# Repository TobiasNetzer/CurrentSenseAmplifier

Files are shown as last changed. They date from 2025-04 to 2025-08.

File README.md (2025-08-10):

## High-Side current sense amplifier for precise current measurement (up to 100mA)
This high-side current sense amplifier is designed to enable accurate current measurement up to 100mA while maintaining a low burden voltage of 1mV/mA.
With a gain of 100, the amplifier produces an output voltage of 100mV/mA.

Documentation
- [Schematic](https://github.com/TobiasNetzer/CurrentSenseAmplifier/blob/main/Documentation/Schematic.pdf)
- [Assembly Drawing](https://github.com/TobiasNetzer/CurrentSenseAmplifier/blob/main/Documentation/Assembly%20Drawing.pdf)
- [BOM](https://htmlpreview.github.io/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)

---

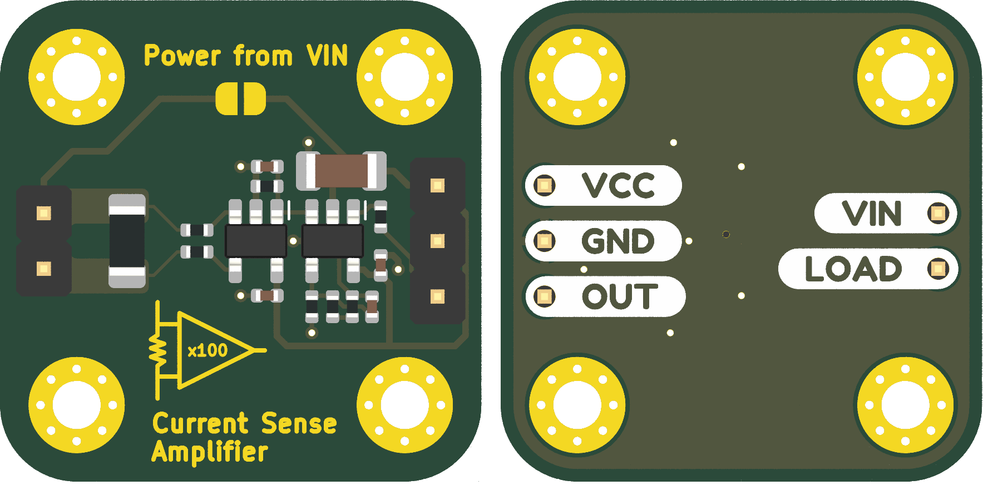
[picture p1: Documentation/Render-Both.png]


---

## Amplifier Accuracy

To test the accuracy of the current sense amplifier, various load currents are applied, and the amplifier’s output is compared to the corresponding load currents. The measurement error is then calculated and plotted as the deviation in percent from the actual value.

Across the tested current range form 5mA - 100mA, the error remained within ±0.2%.

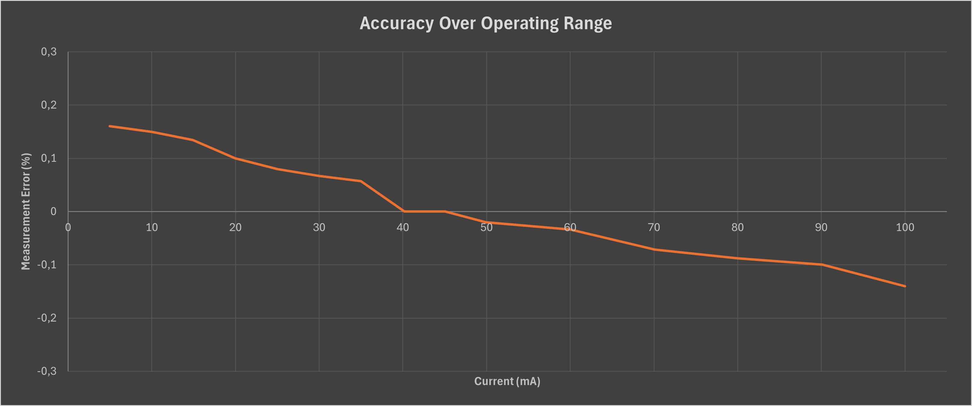
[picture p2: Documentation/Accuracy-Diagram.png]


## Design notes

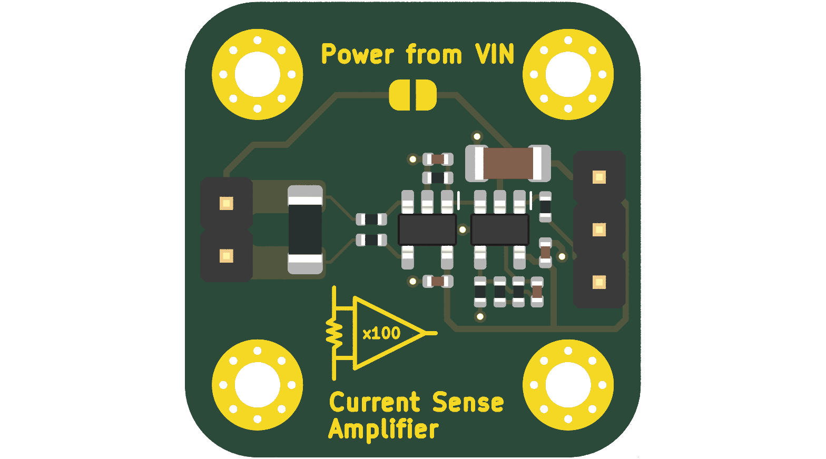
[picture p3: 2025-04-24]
Documentation/Render Top.png

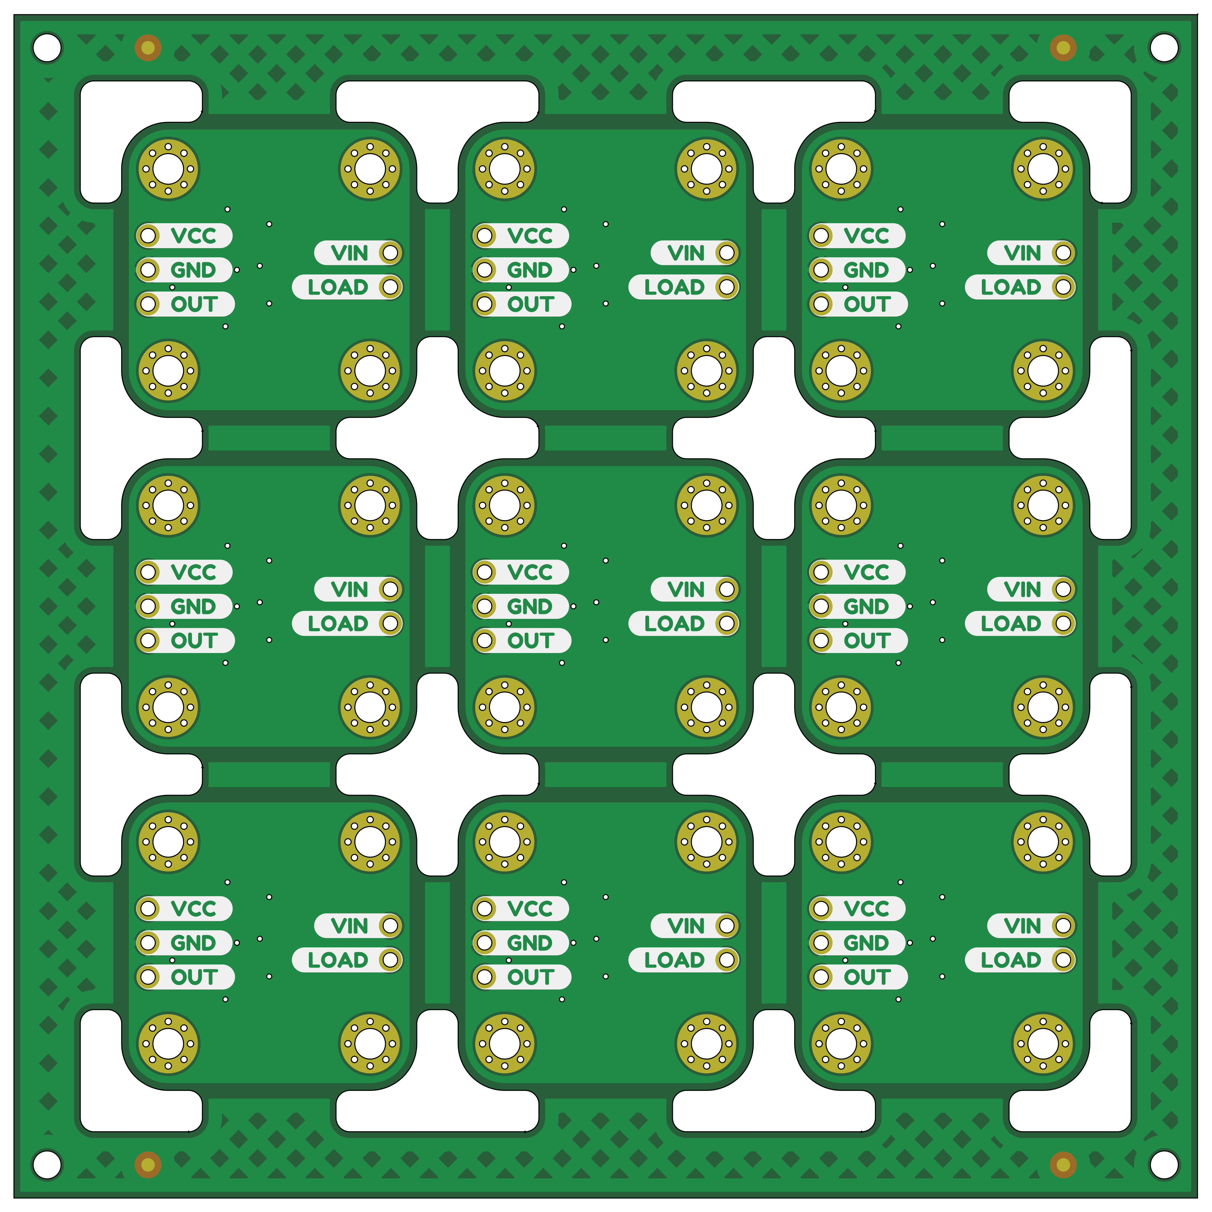
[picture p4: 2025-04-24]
Documentation/Panel Bot Render.png

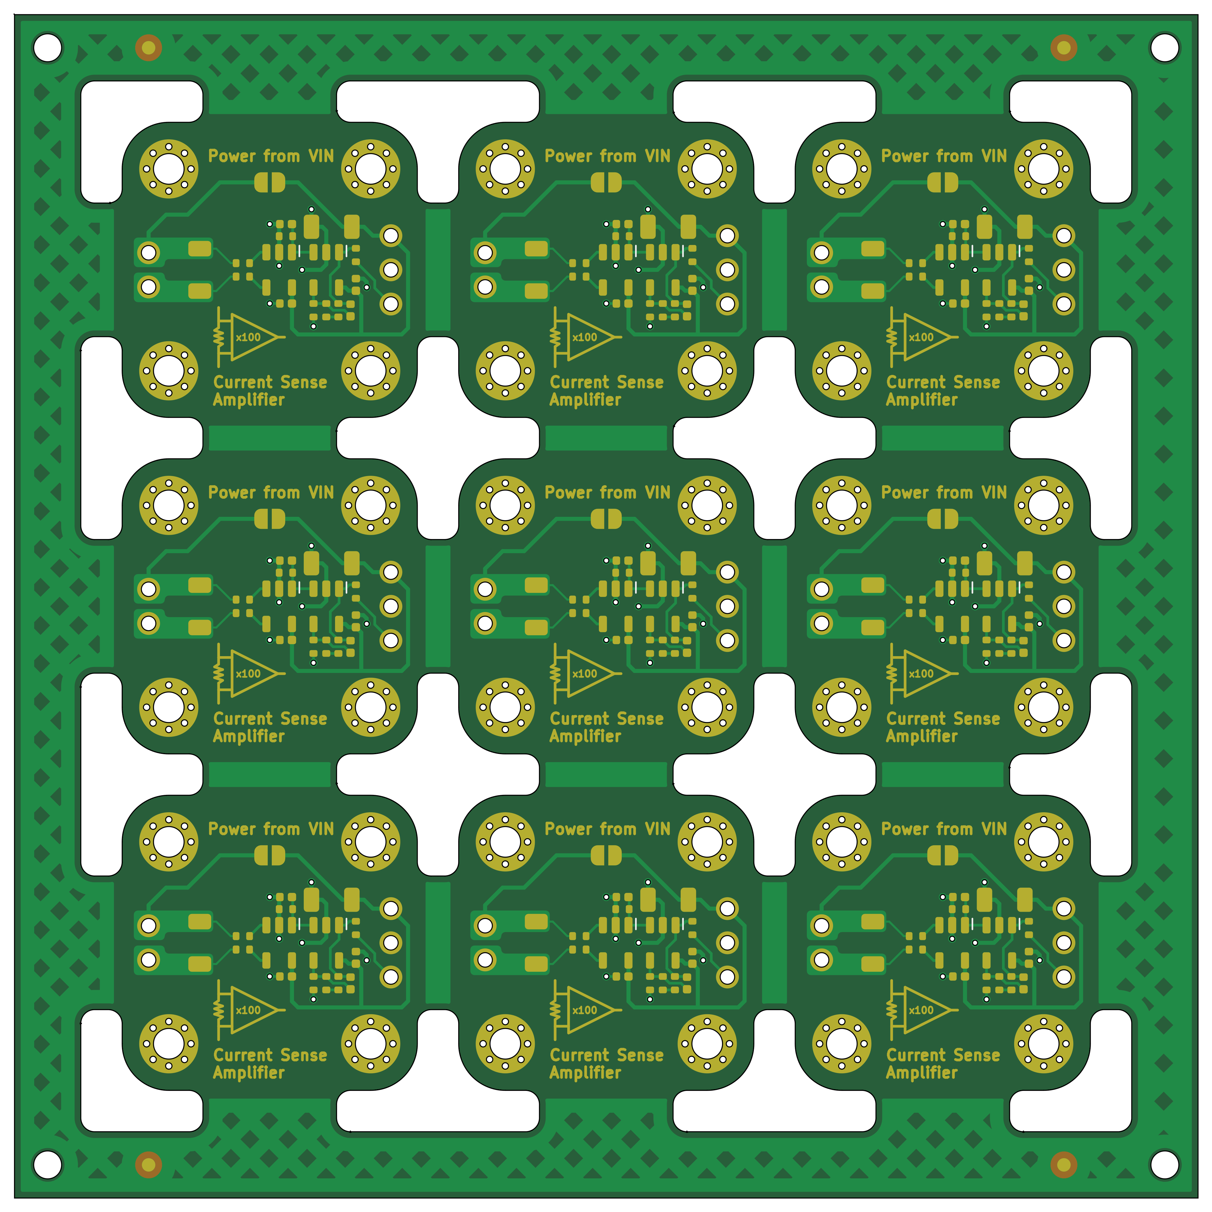
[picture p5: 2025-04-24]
Documentation/Panel Top Render.png

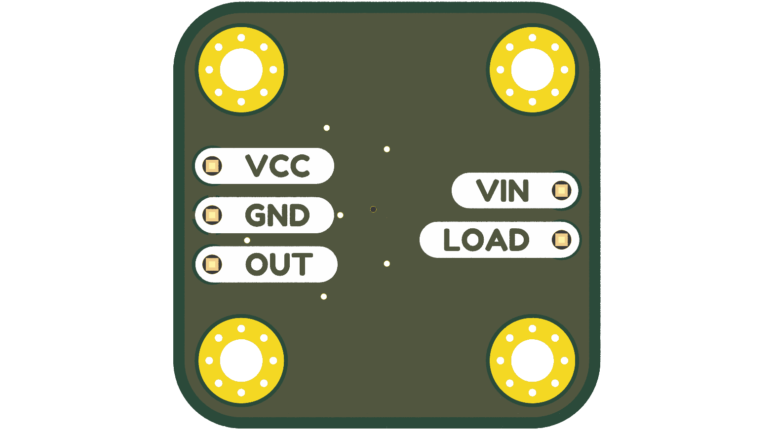
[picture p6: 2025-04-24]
Documentation/Render Bot.png

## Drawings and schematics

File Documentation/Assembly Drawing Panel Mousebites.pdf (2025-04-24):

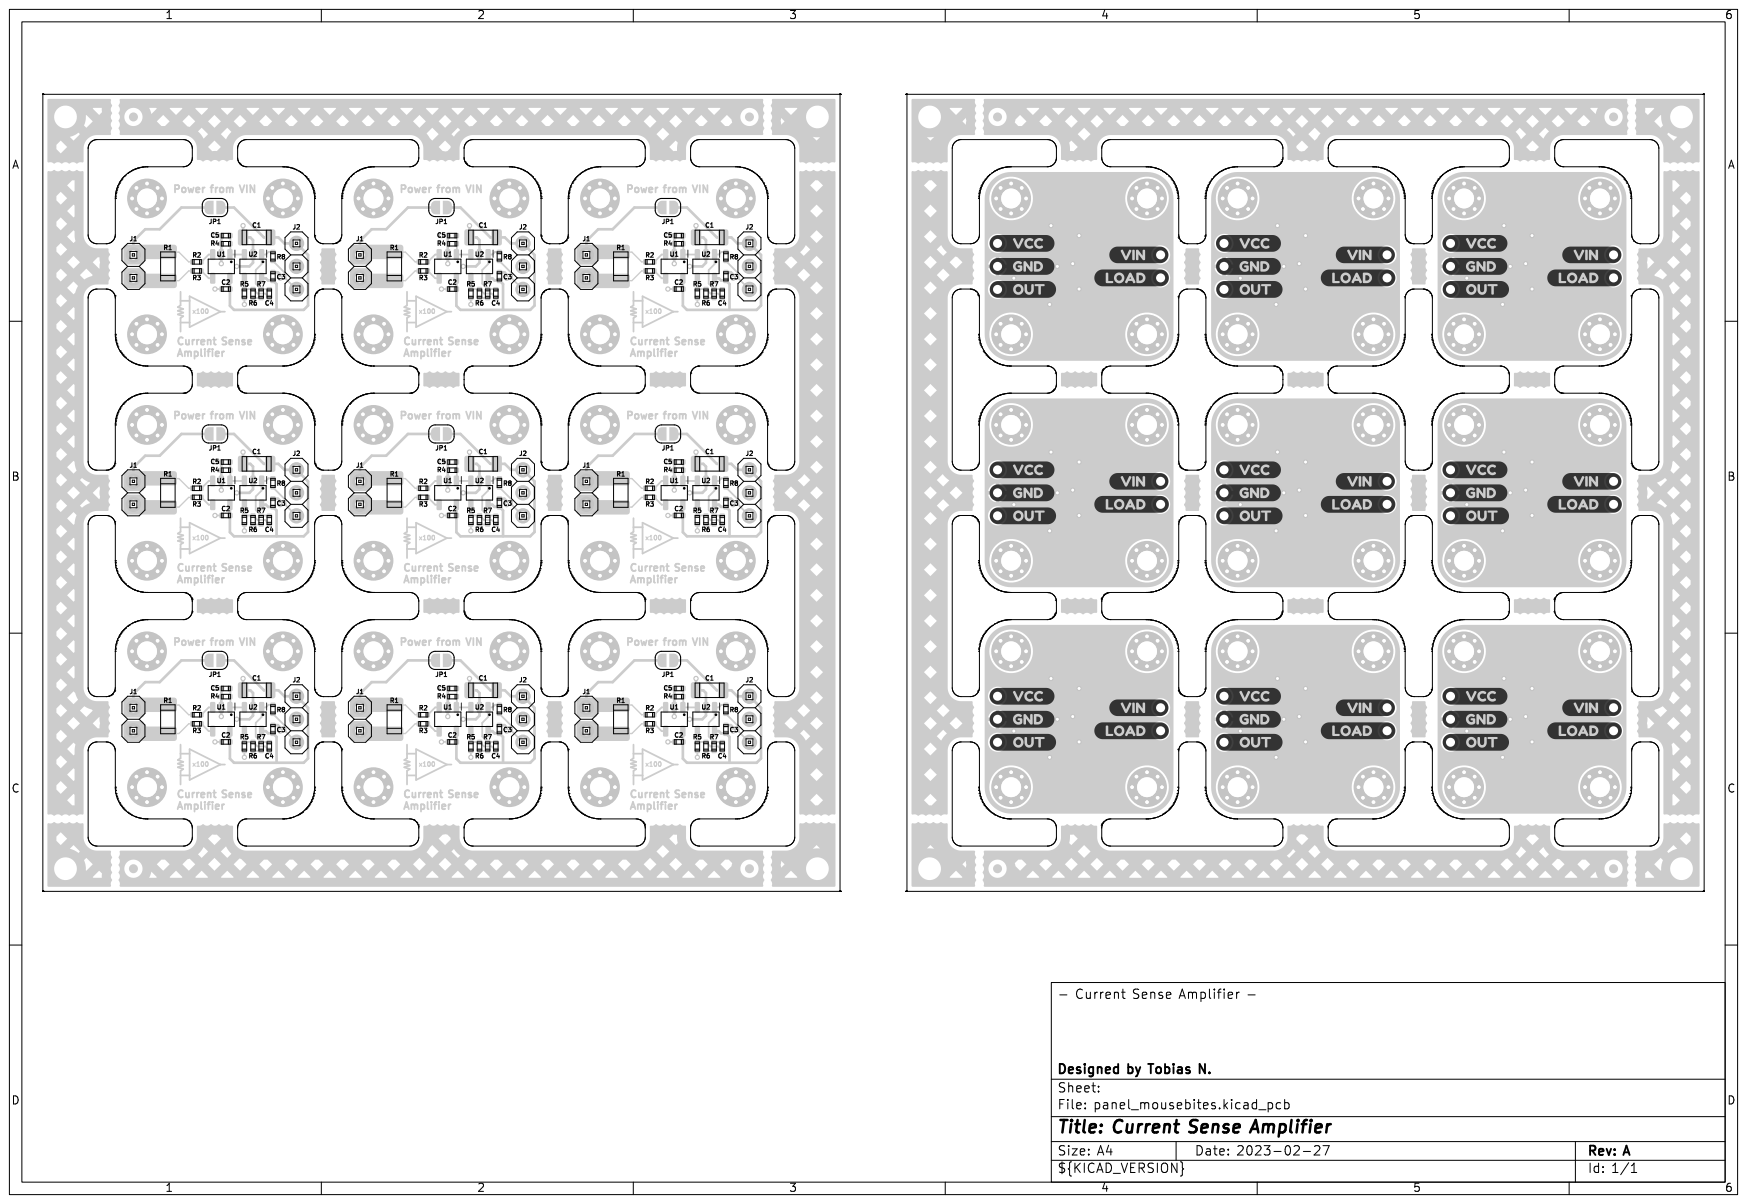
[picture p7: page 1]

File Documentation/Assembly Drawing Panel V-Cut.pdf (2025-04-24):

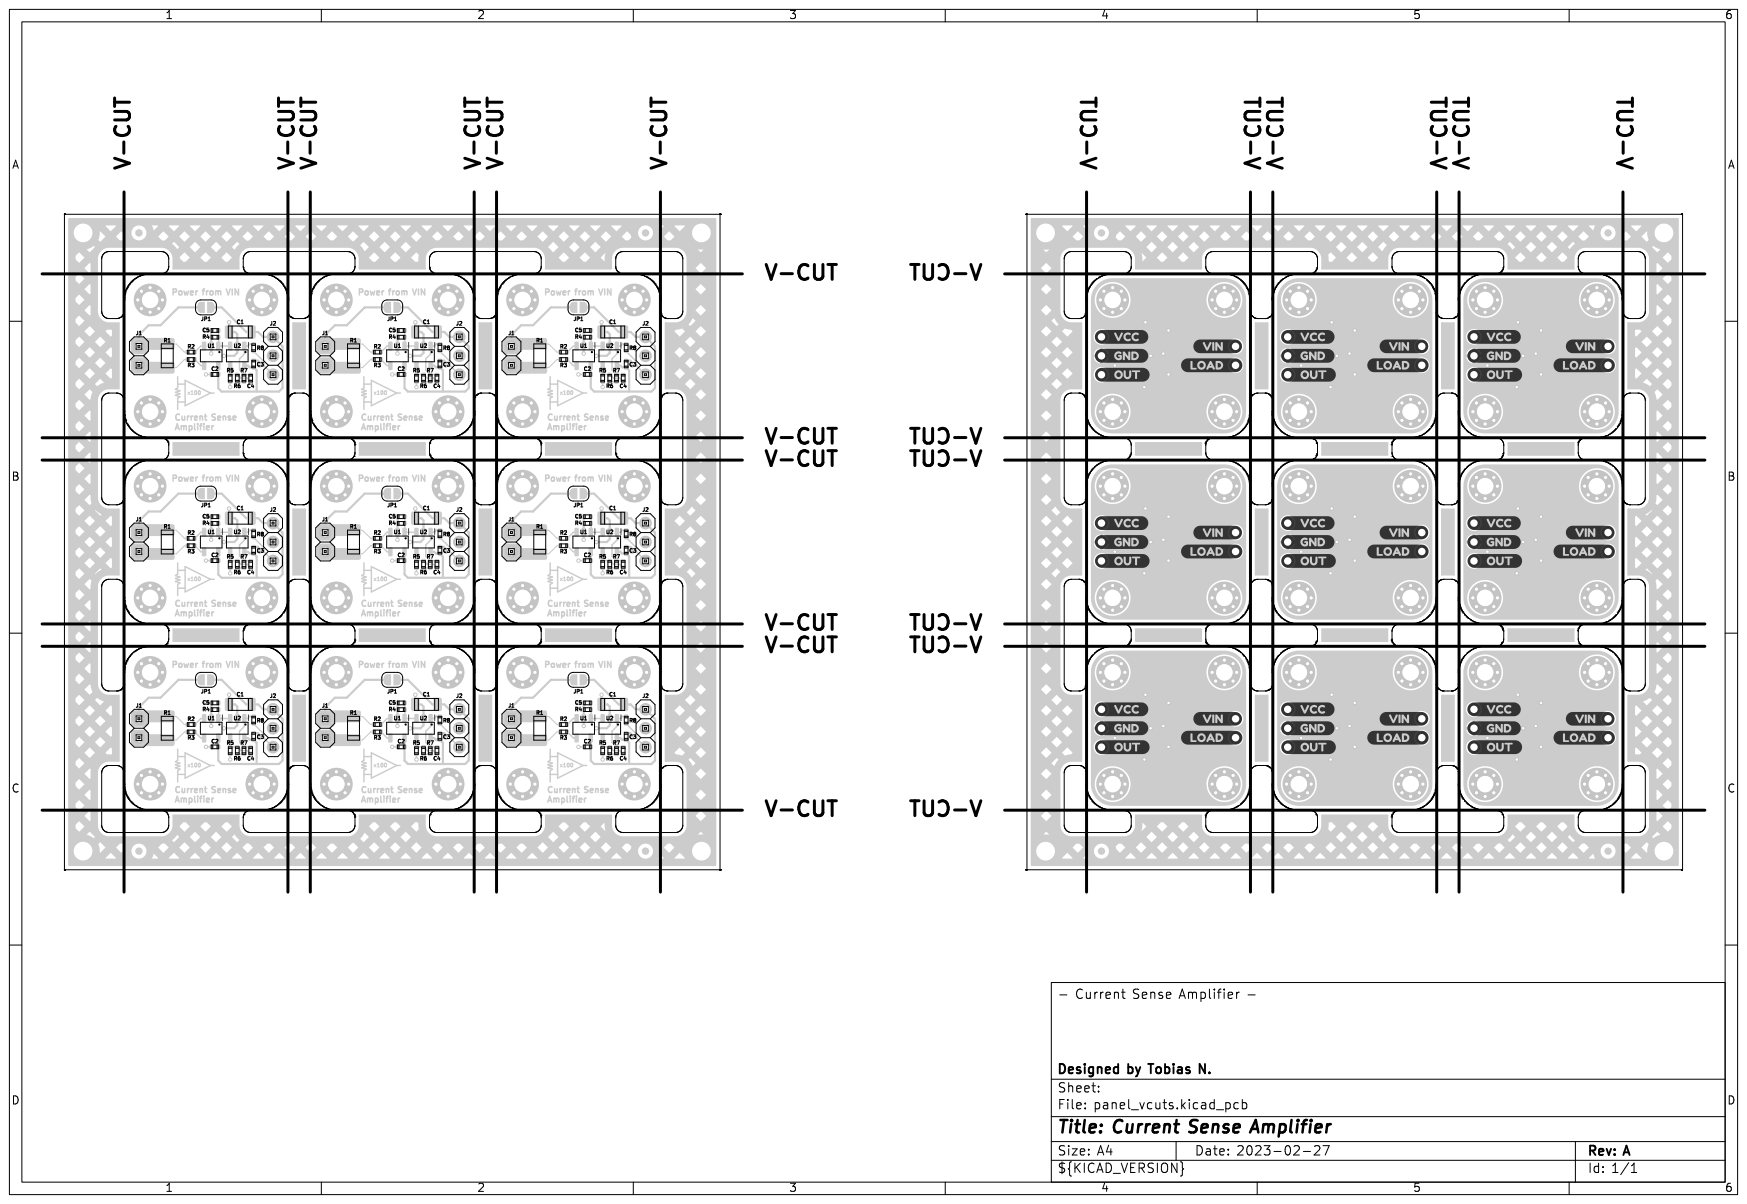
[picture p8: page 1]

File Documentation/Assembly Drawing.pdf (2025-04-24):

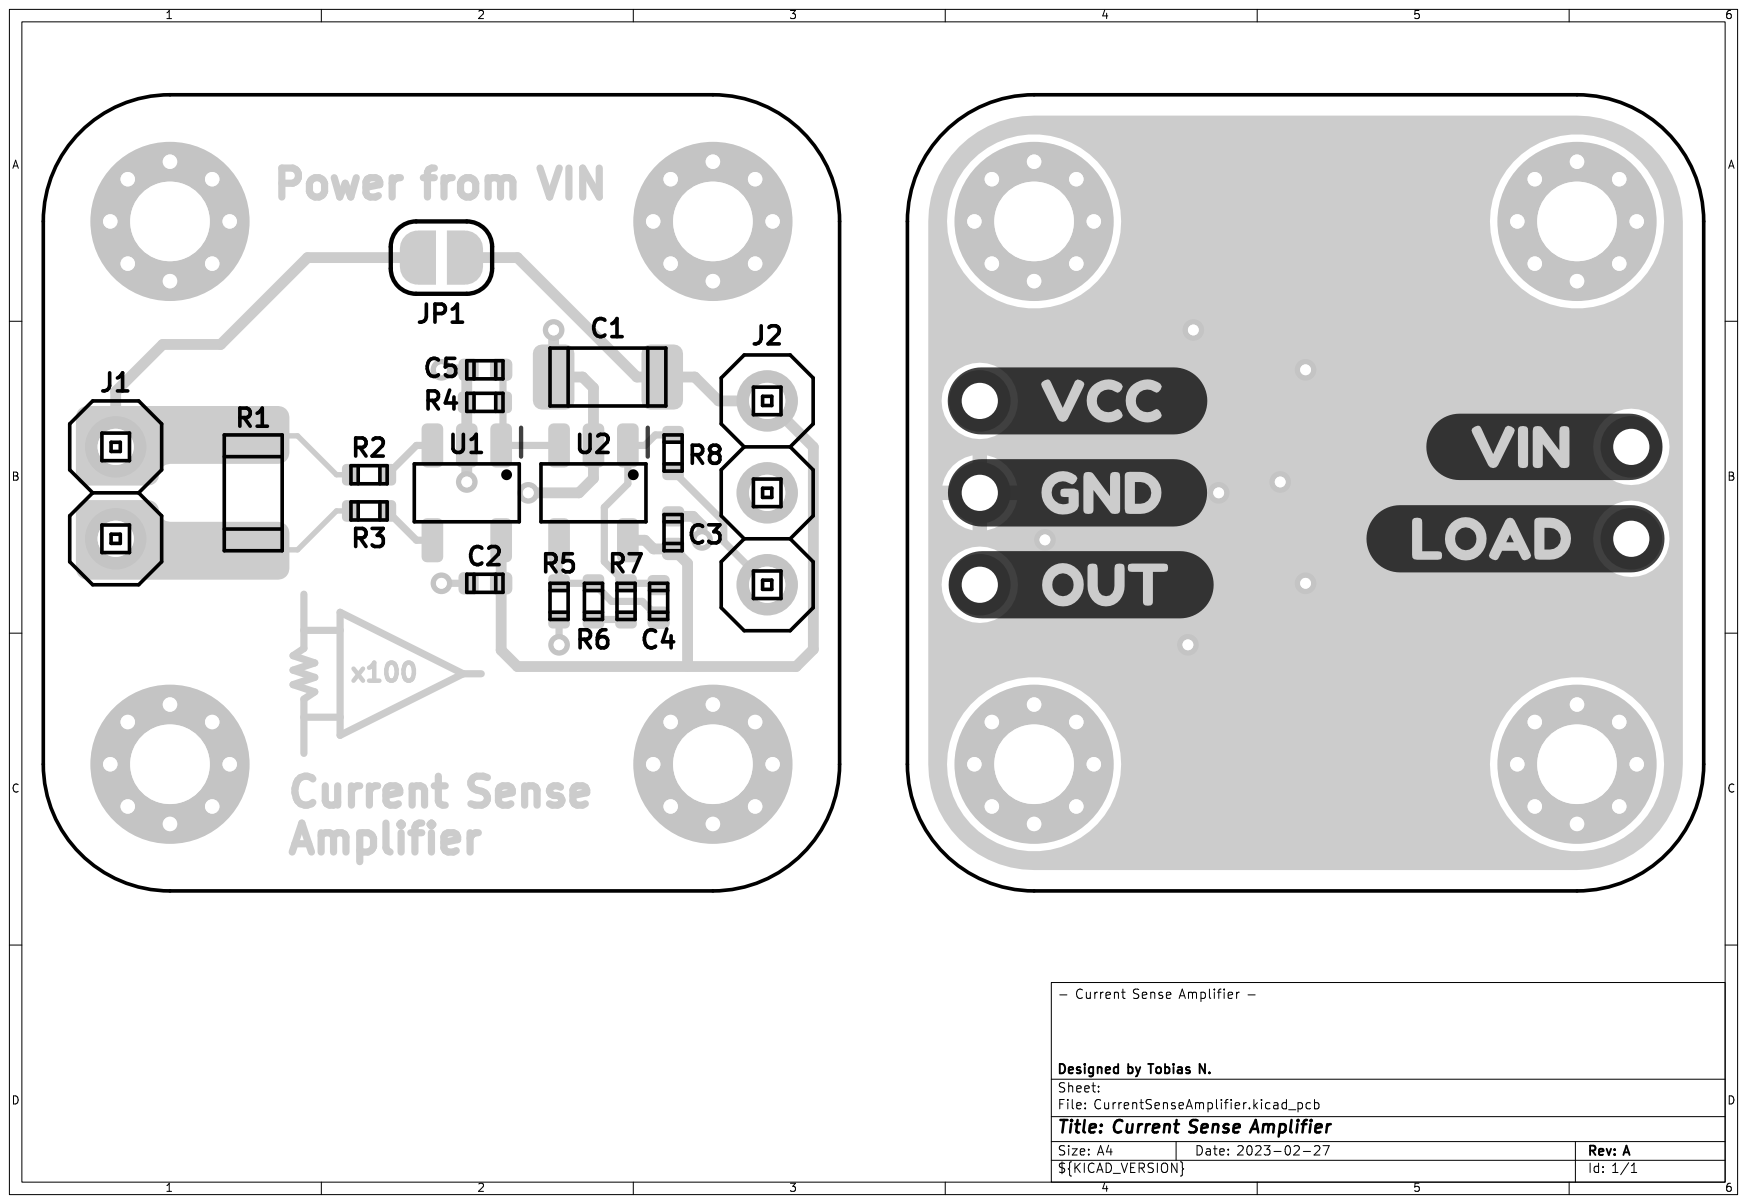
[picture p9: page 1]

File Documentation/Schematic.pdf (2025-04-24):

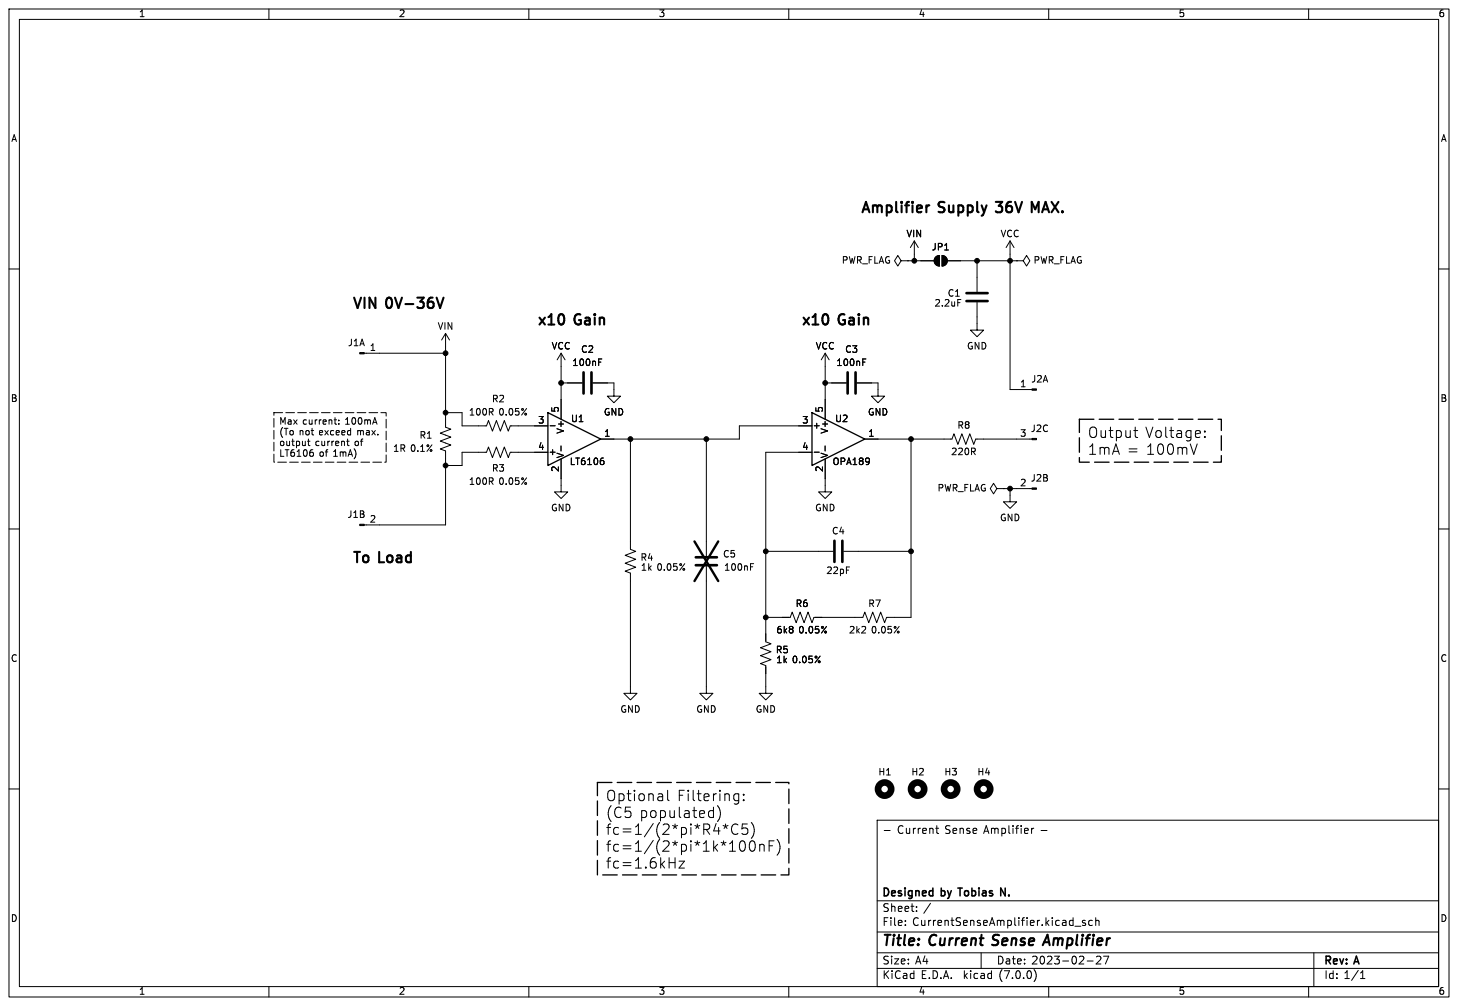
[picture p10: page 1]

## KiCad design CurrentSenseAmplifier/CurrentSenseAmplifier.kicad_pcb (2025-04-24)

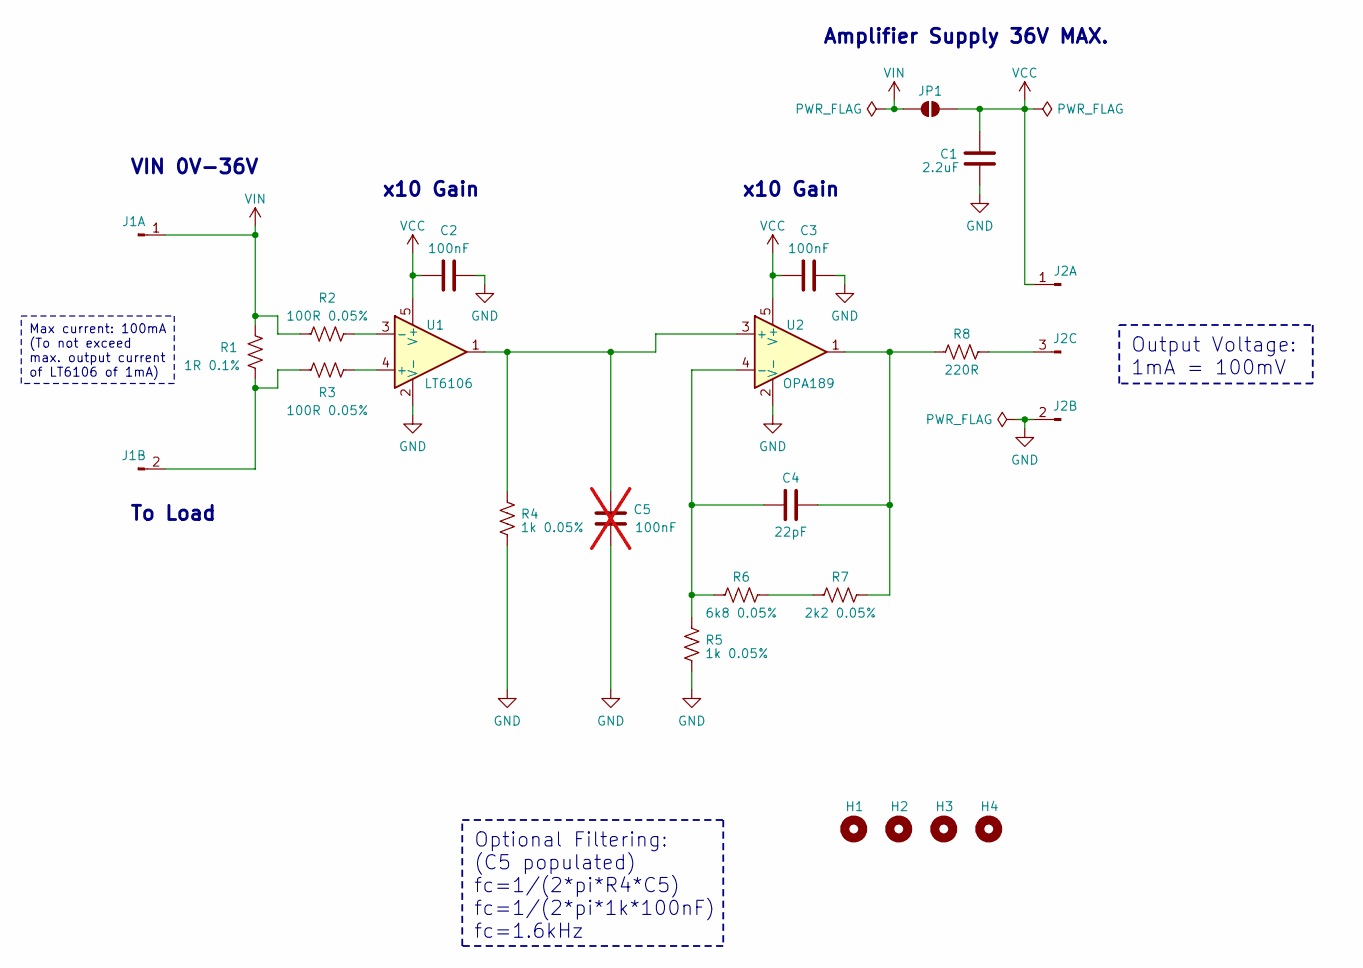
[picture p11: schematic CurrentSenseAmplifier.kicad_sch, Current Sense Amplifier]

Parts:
C1: 2.2uF; C_1206_(3216_Metric); Manufacturer Part Number C1206C225K5RACTU
C2, C3: 100nF; C_0402_(1005_Metric); Manufacturer Part Number C0402C104M3RACTU
C4: 22pF; C_0402_(1005_Metric); Manufacturer Part Number C0402C220J5GACTU
C5: 100nF; C_0402_(1005_Metric); Manufacturer Part Number C0402C104M3RACTU; not fitted
H1, H2, H3, H4: MountingHole; MountingHole_M2
J1: Header_1x03_P2.54; PinHeader_1x02_P2.54mm_Vertical; Manufacturer Part Number TSW-102-08-F-S
J2: Header_1x03_P2.54; PinHeader_1x03_P2.54mm_Vertical; Manufacturer Part Number TSW-103-08-F-S
JP1: SolderJumper_2; SolderJumper-2
R1: 1R 0.1%; R_1206_(3216_Metric); Manufacturer Part Number CPF1206B1R0E1
R2, R3: 100R 0.05%; R_0402_(1005_Metric); Manufacturer Part Number RG1005N-101-W-T5
R4, R5: 1k 0.05%; R_0402_(1005_Metric); Manufacturer Part Number RG1005V-102-W-T1
R6: 6k8 0.05%; R_0402_(1005_Metric); Manufacturer Part Number ERA-2VRW6801X
R7: 2k2 0.05%; R_0402_(1005_Metric); Manufacturer Part Number ERA-2VRW2201X
R8: 220R; R_0402_(1005_Metric); Manufacturer Part Number RC0402FR-13220RL
U1: LT6106; SOT-23-5; Manufacturer Part Number LT6106IS5#TRMPBF
U2: OPA189; SOT-23-5; Manufacturer Part Number OPA189IDBVR

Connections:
GND: C1.2, C2.2, C3.2, C5.2, J2.2, R4.1, R5.1, U1.2 (V-), U2.2 (V-)
unnamed: C4.2, R7.2, R8.1, U2.1
unnamed: J1.2, R1.2, R3.1
unnamed: J2.3, R8.2
unnamed: R6.2, R7.1
unnamed: R3.2, U1.4 (+)
unnamed: R2.2, U1.3 (-)
unnamed: C5.1, R4.2, U1.1, U2.3 (+)
unnamed: C4.1, R5.2, R6.1, U2.4 (-)
VCC: C1.1, C2.1, C3.1, J2.1, JP1.2 (B), U1.5 (V+), U2.5 (V+)
VIN: J1.1, JP1.1 (A), R1.1, R2.1

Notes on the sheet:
Output Voltage: 1mA = 100mV
Optional Filtering: (C5 populated) fc=1/(2*pi*R4*C5) fc=1/(2*pi*1k*100nF) fc=1.6kHz
Max current: 100mA (To not exceed max. output current of LT6106 of 1mA)
x10 Gain
VIN 0V-36V
To Load
Amplifier Supply 36V MAX.

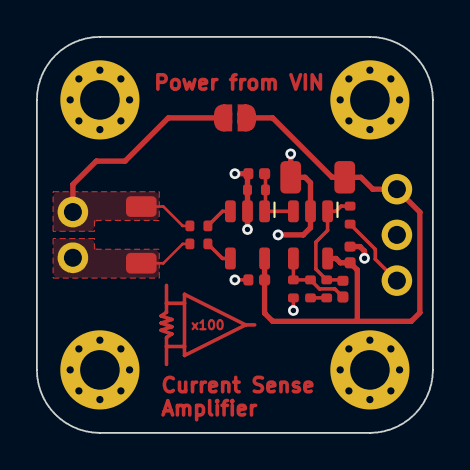
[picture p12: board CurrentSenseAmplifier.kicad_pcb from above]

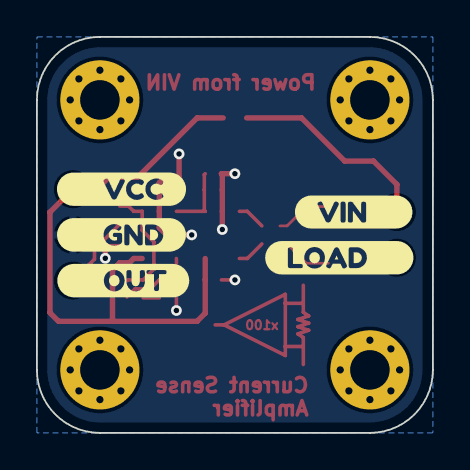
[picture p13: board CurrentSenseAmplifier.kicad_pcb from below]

Board: 2 copper layers, 22.0 x 22.0 mm, 27 parts (5 on the bottom side), 11 nets.

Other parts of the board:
kibuzzard-64025D5B: G***; kibuzzard-64025D5B
kibuzzard-64025D53: G***; kibuzzard-64025D53
kibuzzard-64025D67: G***; kibuzzard-64025D67
kibuzzard-64027212: G***; kibuzzard-64027212
kibuzzard-64027225: G***; kibuzzard-64027225
